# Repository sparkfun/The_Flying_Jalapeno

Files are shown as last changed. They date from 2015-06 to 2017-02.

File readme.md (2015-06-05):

The Flying Jalapeno
=======

This is a generic testbed board that will act as the "brain and usual hardware" for 99% of testbeds. We currently design a ton of testbeds using the pro mini, but this requires us to also put more circuitry on the testbed itself. Since we use basically the same extra stuff on every testbed, it makes sense to have a custom board that includes all of this.

It will be strictly used in QC and production (a sub assembly). 

The title "The Flying Jalapeno". I know I'm a dork, but hey, might as well name it something fun. And why not be in honor of the best AVC team name ever??

The extra hardware necessary for most testbeds:

-2 adjustable vregs with high-side switches
-2 resistor groups used for pre-testing for shorts to GND
-2 IOs setup for capsense (basically just 10M resistors for each "send" line)
-Resistors in place for PASS/FAIL leds
-Larger Vreg for VCC, to make more current available as needed
-Universal connector (2/18 header) that will mate with future pogobeds. (The idea here is that most future pogobeds will be comprised of two things: (2) the FLying Jalapeno and (2) the custom pogopin hardware.
-1x6 SMD FTDI RA header for easy programming and debug

License Information
-------------------

All of the designs in this repo are public domain but you buy me a beer if you use this and we meet someday ([Beerware license](http://en.wikipedia.org/wiki/Beerware)).

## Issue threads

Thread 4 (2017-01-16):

Capsense Methodology and Design

ericorosel, 2017-01-16:
IMO the capsense methodology could be improved.

We could save IO by sharing a return pin for both built-in capsense pads. This would also allow that pin to be broken-out for use on another capsense pad if it is added to the test-bed PCB.

This brings up 2 potential (not really) issues that I can think of:

(1) I'm not sure the MEGA is capable of sharing return lines. I see no reason why it wouldn't be able to based on how capsense functions, but I have not officially verified this.

(2) If there is an issue with the capsense lines on the FJ then this could affect both capsense pads instead of just one. This is also not really an issue seeing as these subs get tested in production and would not pass functional testing anyways.

Closed 2020-05-06.

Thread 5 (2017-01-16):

Net Naming Changes for Ease of Use

ericorosel, 2017-01-16:
For nets currently named PB0, PB1, PB2, and PB3 it would be nice if the net names would also reflect the digital pins that they represent in the pin definitions for the chip in Arduino eg.  53/PB0, 52/PB1, etc.

IMO, this naming convention should also be carried over to all of the serial lines: RX1/TX1 - RX3/TX3. I think we can omit RX0 and TX0, as those lines are not broken out to the test-bed and are dedicated programming and debug lines for the FJ.

Closed 2020-05-06.

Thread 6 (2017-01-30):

Pre set pins and naming

ericorosel, 2017-01-30:
I don't see a need in naming pins 40-43 any thing other than just default LED. In the chance that these LEDs are used as something other than PASS/FAIL LEDs it creates unneeded confusion.

I say leave it up to the designer to name the net between the pin and the LED symbol using the net as a descriptor for LED function.

Closed 2020-05-06.

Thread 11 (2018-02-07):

Add a pretest circuit for testing of board VCC

ericorosel, 2018-02-07:
for test-boards with an on-board vreg, it would be nice to have a pretest circuit built into the FJ so that one could test the VCC line for shorts. This would also allow one to check for proper regulator function. I believe currently the pretest circuits are defaulted to v1 and v2.

I suppose you could connect VCC (post on-board vreg) to v1 or v2, not power up that line, and just utilize the pretest circuit, but it seems a little wonky... Especially with some of the power control issues we've seen in the past.

ericorosel, 2020-04-28:
I'm not sure this is worth doing. I will be breaking out the FJ VCC to a pin on the connector to run switches, etc.

Closed 2020-04-28.

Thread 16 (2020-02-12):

Remove PCA from design

ericorosel, 2020-02-12:
Having logic conversion hardwired into the FJ design is unnecessary and causes more issues than it helps. If logic conversion is necessary per an assembly, we can add the appropiate parts to the daughter board

ericorosel, 2020-05-06:
Removed from new design, can use the PCA recomended replacement or create a LL conversion circuit using N Channel mosfet and pullups.

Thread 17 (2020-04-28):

Additions for FJ rev

ericorosel, 2020-04-28:
-add pins that breakout the output of V1 and V2 before the switch - power aux pins
-swap jumper for switch controlling FJ logic level
-add freqread and freqcount pins from paul's lib (47 for count, 49 for measure)

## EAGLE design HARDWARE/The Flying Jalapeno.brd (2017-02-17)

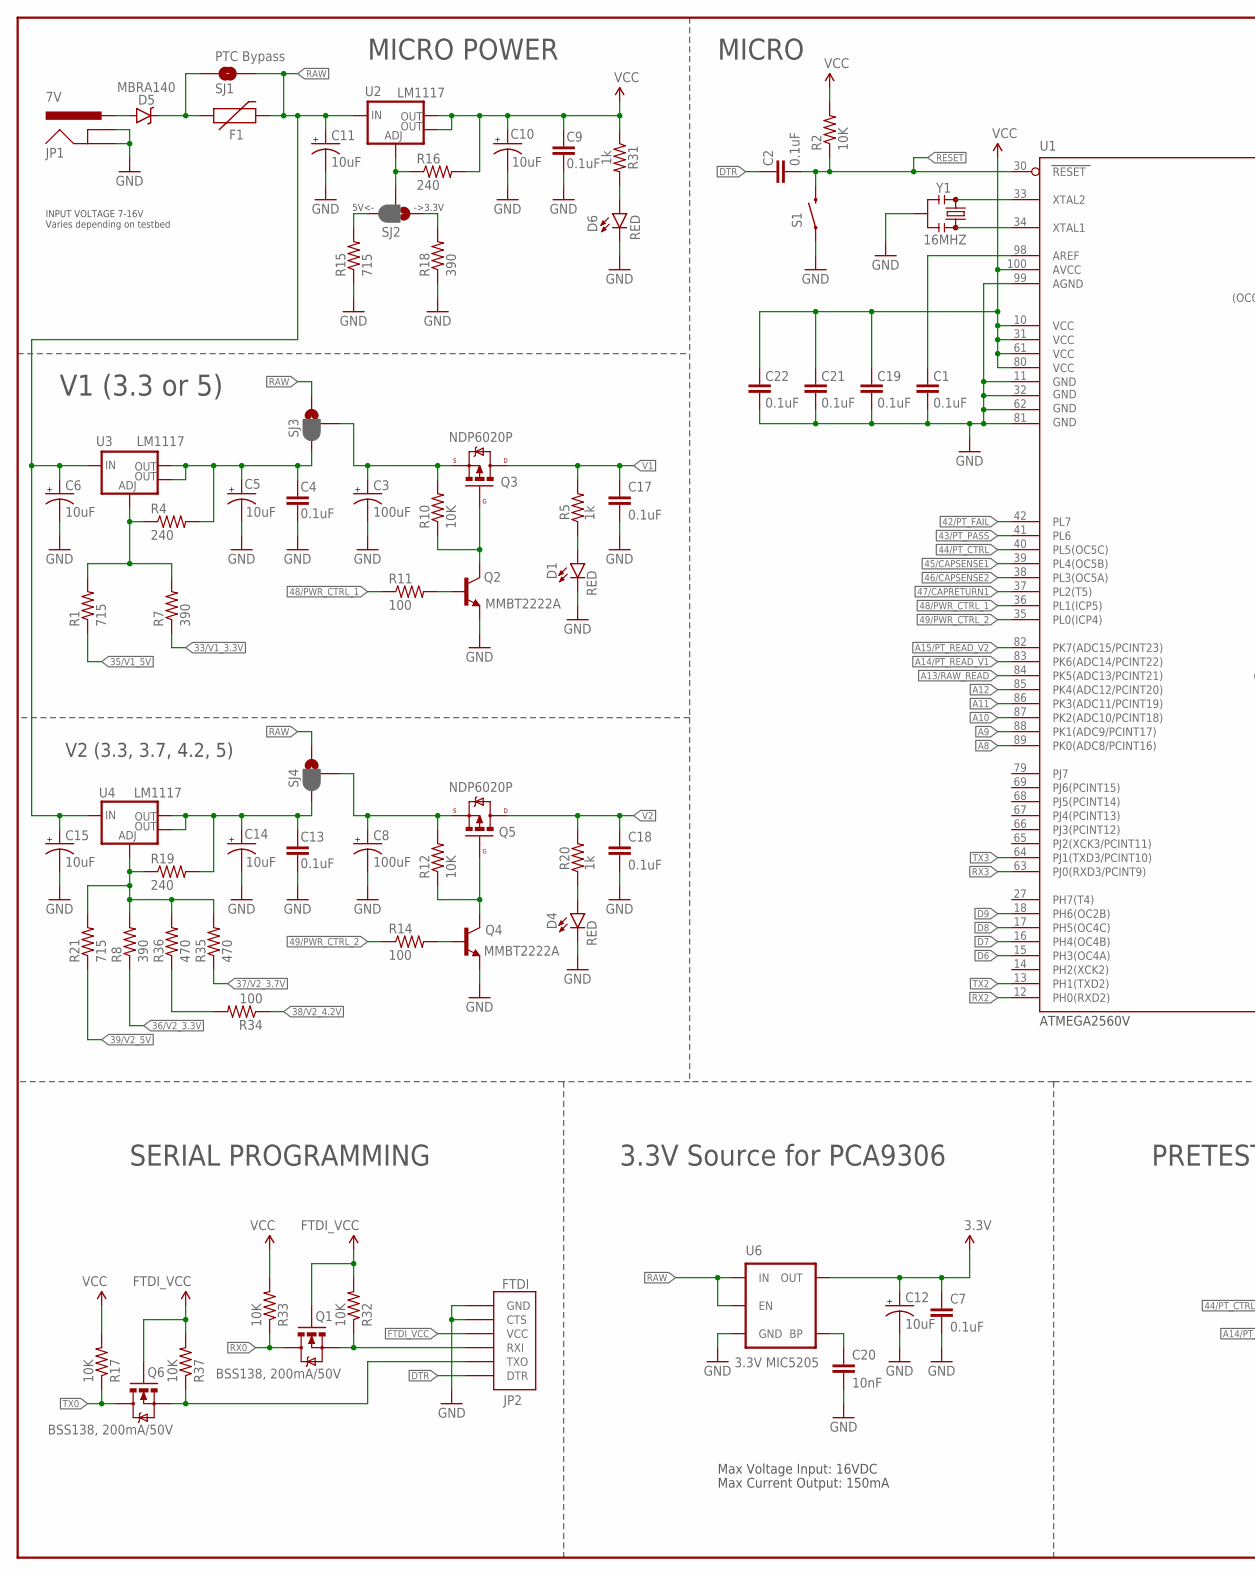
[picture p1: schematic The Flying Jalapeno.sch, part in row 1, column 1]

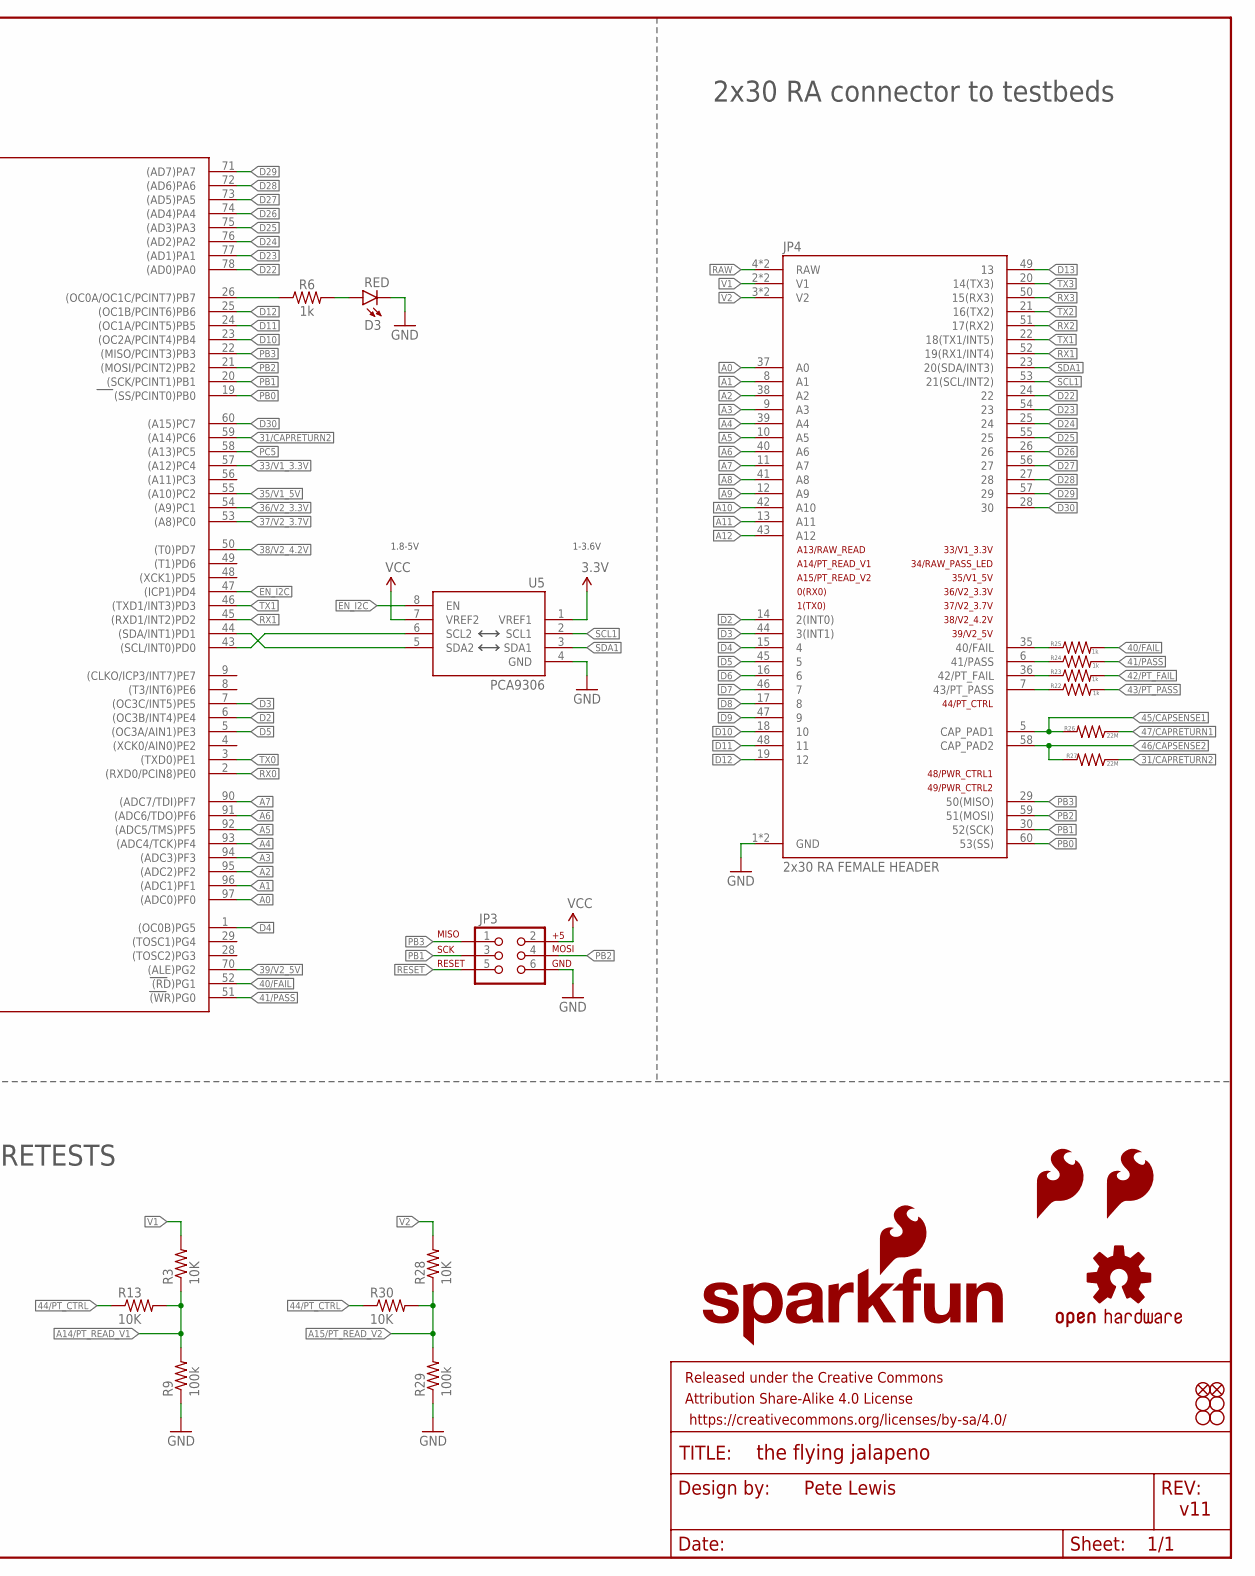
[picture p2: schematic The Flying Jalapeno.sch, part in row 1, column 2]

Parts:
C1, C2, C4, C7, C9, C13, C17, C18, C19, C21, C22: 0.1uF; 0603-CAP
C3, C8: 100uF; NIC_10X10.5_CAP
C5, C6, C10, C11, C14, C15: 10uF; EIA3216
C12: 10uF; 0603-POL
C20: 10nF; 0603
D1, D3, D4, D6: RED; LED-1206
D5: MBRA140; SMA-DIODE
F1: PTCTHERMISTOR1206; PTC-1206
FRAME1: FRAME-LEDGER; CREATIVE_COMMONS
JP1: 7V; POWER_JACK_PTH_LOCK
JP2: FTDI; FTDI_DEVICE_RA_SMT
JP3: AVR_SPI_PRG_6PTH; 2X3
JP4: 2x30 RA FEMALE HEADER; FLYING_JALAPENO_V3_F
JP5, JP8: FIDUCIALUFIDUCIAL; MICRO-FIDUCIAL
LOGO1: SFE_LOGO_NAME_FLAME.5_INCH; SFE_LOGO_NAME_FLAME_.5
LOGO2: SFE_LOGO_FLAME.3_INCH; SFE_LOGO_FLAME_.3
LOGO3: SFE_LOGO_FLAME.1_INCH; SFE_LOGO_FLAME_.1
LOGO4: OSHW-LOGOL; OSHW-LOGO-L
Q1, Q6: BSS138, 200mA/50V; SOT23-3
Q2, Q4: MMBT2222A; SOT23-3
Q3, Q5: NDP6020P; TO220V
R1, R15, R21: 715; 0603-RES
R2, R3, R10, R12, R13, R17, R28, R30, R32, R33, R37: 10K; 0603-RES
R4, R16, R19: 240; 0603-RES
R5, R6, R20, R22, R23, R24, R25, R31: 1k; 0603
R7, R8, R18: 390; 0603-RES
R9, R29: 100k; 0603-RES
R11, R14, R34: 100; 0603-RES
R26, R27: 22M; 0603-RES
R35, R36: 470; 0603-RES
S1: SWITCH-MOMENTARY-2SMD-REDUNDANT; TACTILE-SWITCH-SMD
SJ1: PTC Bypass; PAD-JUMPER-2-NO_NO_SILK
SJ2, SJ3, SJ4: JUMPER-PAD-3-2OF3_NC_BY_PASTE; PAD-JUMPER-3-2OF3_NC_BY_PASTE_YES_SILK_FULL_BOX
STANDOFF1, STANDOFF2, STANDOFF3, STANDOFF4: STAND-OFFTIGHT; STAND-OFF-TIGHT
U1: ATMEGA2560AU; TQFP100
U2, U3, U4: LM1117; SOT223
U5: PCA9306; PCA9306DC-1:1
U6: 3.3V MIC5205; SOT23-5
Y1: 16MHZ; RESONATOR-SMD

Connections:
3.3V: C7.1, C12.A (+), U5.1 (VREF1), U6.5 (OUT)
31/CAPRETURN2: R27.1, U1.59 ((A14)PC6)
33/V1_3.3V: R7.1, U1.57 ((A12)PC4)
35/V1_5V: R1.1, U1.55 ((A10)PC2)
36/V2_3.3V: R8.1, U1.54 ((A9)PC1)
37/V2_3.7V: R35.1, U1.53 ((A8)PC0)
38/V2_4.2V: R34.1, U1.50 ((T0)PD7)
39/V2_5V: R21.1, U1.70 ((ALE)PG2)
40/FAIL: R25.2, U1.52 ((RD)PG1)
41/PASS: R24.2, U1.51 ((WR)PG0)
42/PT_FAIL: R23.2, U1.42 (PL7)
43/PT_PASS: R22.2, U1.41 (PL6)
44/PT_CTRL: R13.1, R30.1, U1.40 (PL5(OC5C))
45/CAPSENSE1: JP4.5 (CAP_PAD1), R26.2, U1.39 (PL4(OC5B))
46/CAPSENSE2: JP4.58 (CAP_PAD2), R27.2, U1.38 (PL3(OC5A))
47/CAPRETURN1: R26.1, U1.37 (PL2(T5))
48/PWR_CTRL_1: R11.1, U1.36 (PL1(ICP5))
49/PWR_CTRL_2: R14.1, U1.35 (PL0(ICP4))
A0: JP4.37 (A0), U1.97 ((ADC0)PF0)
A1: JP4.8 (A1), U1.96 ((ADC1)PF1)
A2: JP4.38 (A2), U1.95 ((ADC2)PF2)
A3: JP4.9 (A3), U1.94 ((ADC3)PF3)
A4: JP4.39 (A4), U1.93 ((ADC4/TCK)PF4)
A5: JP4.10 (A5), U1.92 ((ADC5/TMS)PF5)
A6: JP4.40 (A6), U1.91 ((ADC6/TDO)PF6)
A7: JP4.11 (A7), U1.90 ((ADC7/TDI)PF7)
A8: JP4.41 (A8), U1.89 (PK0(ADC8/PCINT16))
A9: JP4.12 (A9), U1.88 (PK1(ADC9/PCINT17))
A10: JP4.42 (A10), U1.87 (PK2(ADC10/PCINT18))
A11: JP4.13 (A11), U1.86 (PK3(ADC11/PCINT19))
A12: JP4.43 (A12), U1.85 (PK4(ADC12/PCINT20))
A13/RAW_READ: U1.84 (PK5(ADC13/PCINT21))
A14/PT_READ_V1: R3.1, R9.2, R13.2, U1.83 (PK6(ADC14/PCINT22))
A15/PT_READ_V2: R28.1, R29.2, R30.2, U1.82 (PK7(ADC15/PCINT23))
AREF: C1.2, U1.98 (AREF)
D2: JP4.14 (2(INT0)), U1.6 ((OC3B/INT4)PE4)
D3: JP4.44 (3(INT1)), U1.7 ((OC3C/INT5)PE5)
D4: JP4.15 (4), U1.1 ((OC0B)PG5)
D5: JP4.45 (5), U1.5 ((OC3A/AIN1)PE3)
D6: JP4.16 (6), U1.15 (PH3(OC4A))
D7: JP4.46 (7), U1.16 (PH4(OC4B))
D8: JP4.17 (8), U1.17 (PH5(OC4C))
D9: JP4.47 (9), U1.18 (PH6(OC2B))
D10: JP4.18 (10), U1.23 ((OC2A/PCINT4)PB4)
D11: JP4.48 (11), U1.24 ((OC1A/PCINT5)PB5)
D12: JP4.19 (12), U1.25 ((OC1B/PCINT6)PB6)
D13: JP4.49 (13), R6.1, U1.26 ((OC0A/OC1C/PCINT7)PB7)
D22: JP4.24 (22), U1.78 ((AD0)PA0)
D23: JP4.54 (23), U1.77 ((AD1)PA1)
D24: JP4.25 (24), U1.76 ((AD2)PA2)
D25: JP4.55 (25), U1.75 ((AD3)PA3)
D26: JP4.26, U1.74 ((AD4)PA4)
D27: JP4.56 (27), U1.73 ((AD5)PA5)
D28: JP4.27 (28), U1.72 ((AD6)PA6)
D29: JP4.57 (29), U1.71 ((AD7)PA7)
D30: JP4.28 (30), U1.60 ((A15)PC7)
DTR: C2.2, JP2.1 (DTR)
EN_I2C: U1.47 ((ICP1)PD4), U5.8 (EN)
FTDI_VCC: JP2.4 (VCC), Q1.1 (G), Q6.1 (G), R32.2, R37.2
GND: C1.1, C3.-, C4.2, C5.C (-), C6.C (-), C7.2, C8.-, C9.2, C10.C (-), C11.C (-), C12.K (-), C13.2, C14.C (-), C15.C (-), C17.2, C18.2, C19.1, C20.2, C21.1, C22.1, D1.C, D3.C, D4.C, D6.C, JP1.GND, JP1.GNDBREAK, JP2.5 (CTS), JP2.6 (GND), JP3.6, JP4.1 (GND), JP4.31 (GND), Q2.2 (E), Q4.2 (E), R9.1, R15.1, R18.1, R29.1, S1.1, S1.2 (1), U1.11 (GND), U1.32 (GND1), U1.62 (GND2), U1.81 (GND3), U1.99 (AGND), U5.4 (GND), U6.2 (GND), Y1.2
unnamed: R34.2, R36.1
unnamed: U1.44 ((SDA/INT1)PD1), U5.5 (SDA2)
unnamed: R16.1, SJ2.2, U2.1 (ADJ)
unnamed: D3.A, R6.2
unnamed: D1.A, R5.1
unnamed: JP4.7 (43/PT_PASS), R22.1
unnamed: JP4.36 (42/PT_FAIL), R23.1
unnamed: Q2.1 (B), R11.2
unnamed: R1.2, R4.1, R7.2, U3.1 (ADJ)
unnamed: R8.2, R19.1, R21.2, R35.2, R36.2, U4.1 (ADJ)
unnamed: D4.A, R20.1
unnamed: Q2.3 (C), Q3.1 (G), R10.1
unnamed: Q4.1 (B), R14.2
unnamed: Q4.3 (C), Q5.1 (G), R12.1
unnamed: D5.C, F1.1, SJ1.1
unnamed: JP2.3 (RXI), Q1.2 (S), R32.1
unnamed: R18.2, SJ2.1
unnamed: R15.2, SJ2.3
unnamed: JP4.6 (41/PASS), R24.1
unnamed: JP4.35 (40/FAIL), R25.1
unnamed: C4.1, C5.A (+), R4.2, SJ3.3, U3.2 (OUT), U3.4 (OUT)
unnamed: C3.+, Q3.3 (S), R10.2, SJ3.2
unnamed: C8.+, Q5.3 (S), R12.2, SJ4.2
unnamed: D5.A, JP1.PWR
unnamed: D6.A, R31.2
unnamed: JP2.2 (TXO), Q6.2 (S), R37.1
unnamed: U1.43 ((SCL/INT0)PD0), U5.6 (SCL2)
unnamed: C20.1, U6.4 (BP)
unnamed: U1.33 (XTAL2), Y1.3
unnamed: U1.34 (XTAL1), Y1.1
PB0: JP4.60 (53(SS)), U1.19 ((SS/PCINT0)PB0)
PB1: JP3.3, JP4.30 (52(SCK)), U1.20 ((SCK/PCINT1)PB1)
PB2: JP3.4, JP4.59 (51(MOSI)), U1.21 ((MOSI/PCINT2)PB2)
PB3: JP3.1, JP4.29 (50(MISO)), U1.22 ((MISO/PCINT3)PB3)
PC5: U1.58 ((A13)PC5)
RAW: C6.A (+), C11.A (+), C15.A (+), F1.2, JP4.4 (RAW), JP4.34 (RAW), SJ1.2, SJ3.1, SJ4.1, U2.3 (IN), U3.3 (IN), U4.3 (IN), U6.1 (IN), U6.3 (EN)
RESET: C2.1, JP3.5, R2.1, S1.3 (2), S1.4 (2), U1.30 (RESET)
RX0: Q1.3 (D), R33.1, U1.2 ((RXD0/PCIN8)PE0)
RX1: JP4.52 (19(RX1/INT4)), U1.45 ((RXD1/INT2)PD2)
RX2: JP4.51 (17(RX2)), U1.12 (PH0(RXD2))
RX3: JP4.50 (15(RX3)), U1.63 (PJ0(RXD3/PCINT9))
SCL1: JP4.53 (21(SCL/INT2)), U5.2 (SCL1)
SDA1: JP4.23 (20(SDA/INT3)), U5.3 (SDA1)
TX0: Q6.3 (D), R17.1, U1.3 ((TXD0)PE1)
TX1: JP4.22 (18(TX1/INT5)), U1.46 ((TXD1/INT3)PD3)
TX2: JP4.21 (16(TX2)), U1.13 (PH1(TXD2))
TX3: JP4.20 (14(TX3)), U1.64 (PJ1(TXD3/PCINT10))
V1: C17.1, JP4.2 (V1), JP4.32 (V1), Q3.2 (D), R3.2, R5.2
V2: C18.1, JP4.3 (V2), JP4.33 (V2), Q5.2 (D), R20.2, R28.2
VCC: C9.1, C10.A (+), C19.2, C21.2, C22.2, JP3.2, R2.2, R16.2, R17.2, R31.1, R33.2, U1.10 (VCC), U1.31 (VCC1), U1.61 (VCC2), U1.80 (VCC3), U1.100 (AVCC), U2.2 (OUT), U2.4 (OUT), U5.7 (VREF2)
VREG2OUT: C13.1, C14.A (+), R19.2, SJ4.3, U4.2 (OUT), U4.4 (OUT)

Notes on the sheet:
PRETESTS
MICRO POWER
V1 (3.3 or 5)
V2 (3.3, 3.7, 4.2, 5)
SERIAL PROGRAMMING
MICRO
Pete Lewis
v11
ATMEGA2560V
2x30 RA connector to testbeds
INPUT VOLTAGE 7-16V Varies depending on testbed
->3.3V
5V<-
Max Voltage Input: 16VDC
Max Current Output: 150mA
1.8-5V
1-3.6V
3.3V Source for PCA9306

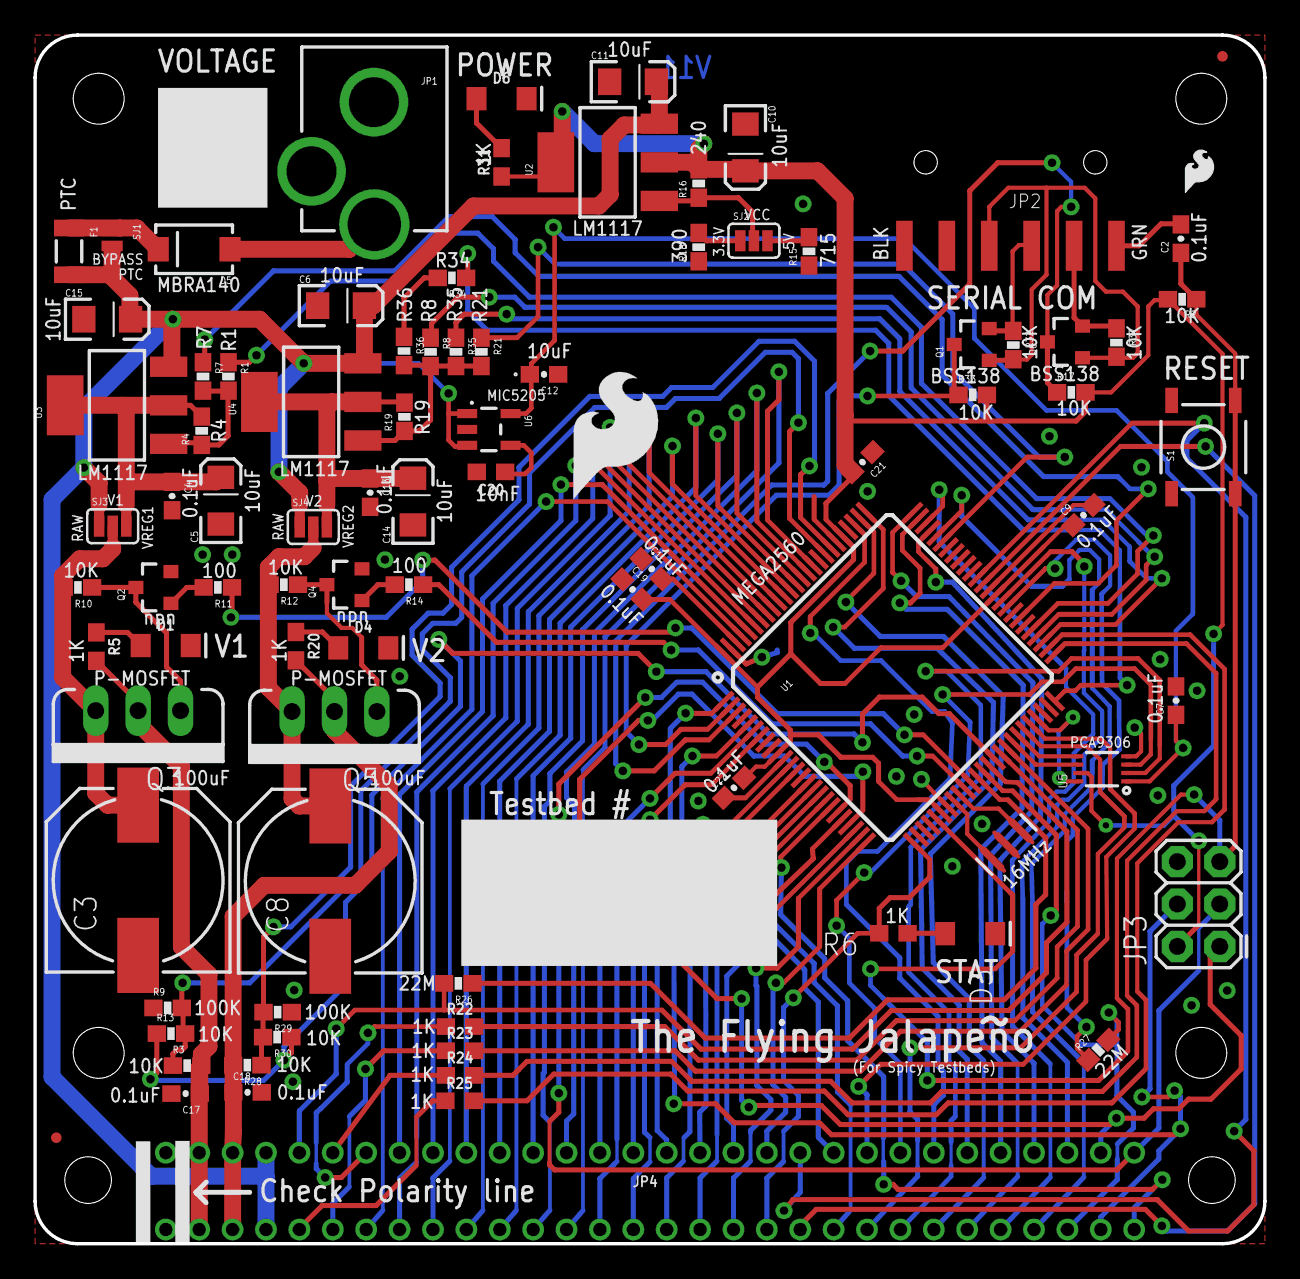
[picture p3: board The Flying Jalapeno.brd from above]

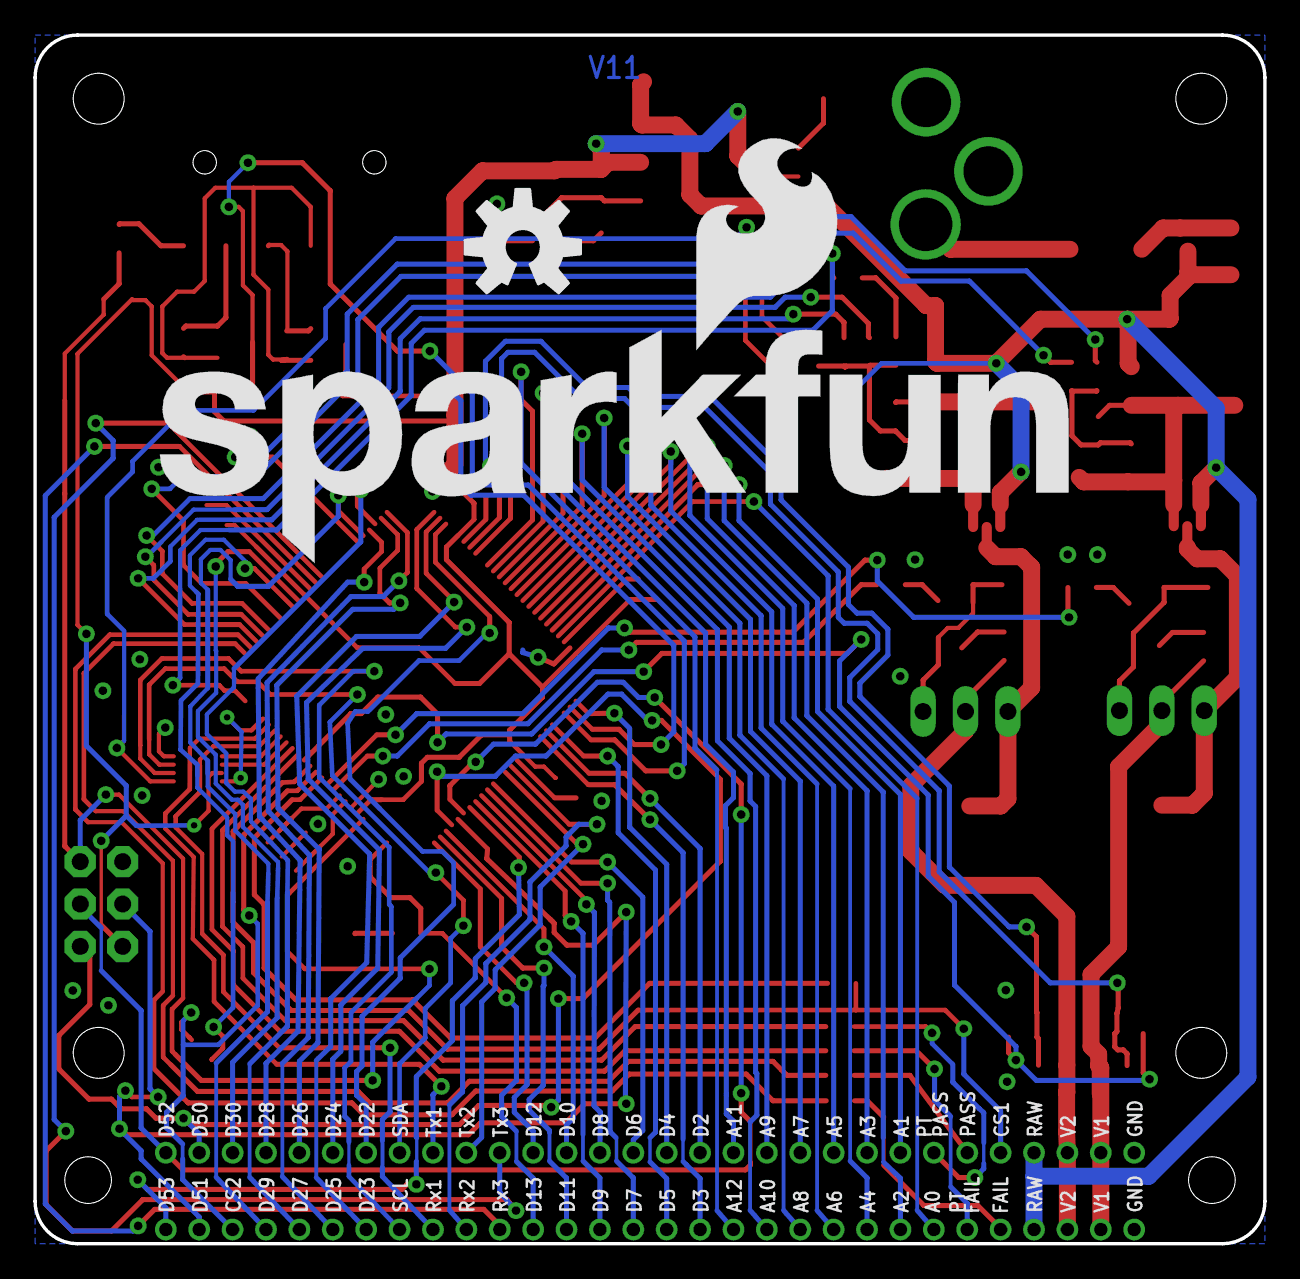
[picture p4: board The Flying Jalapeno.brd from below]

Board: 2 copper layers, 73.7 x 72.4 mm, 97 parts (2 on the bottom side), 109 nets.

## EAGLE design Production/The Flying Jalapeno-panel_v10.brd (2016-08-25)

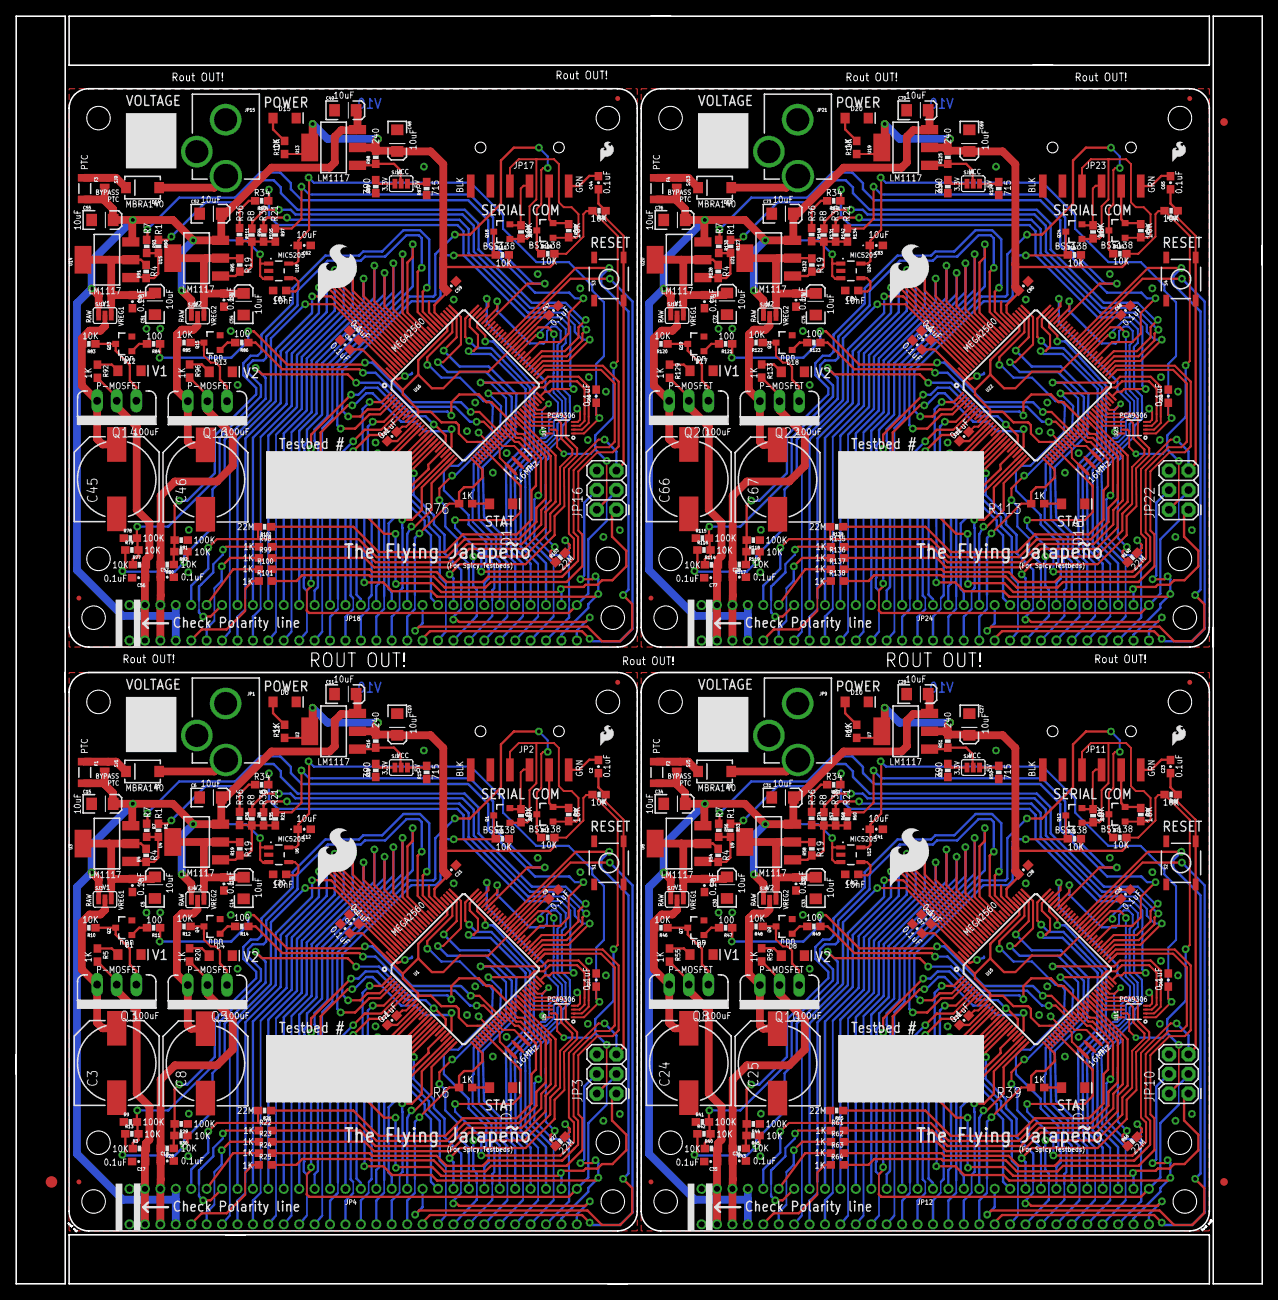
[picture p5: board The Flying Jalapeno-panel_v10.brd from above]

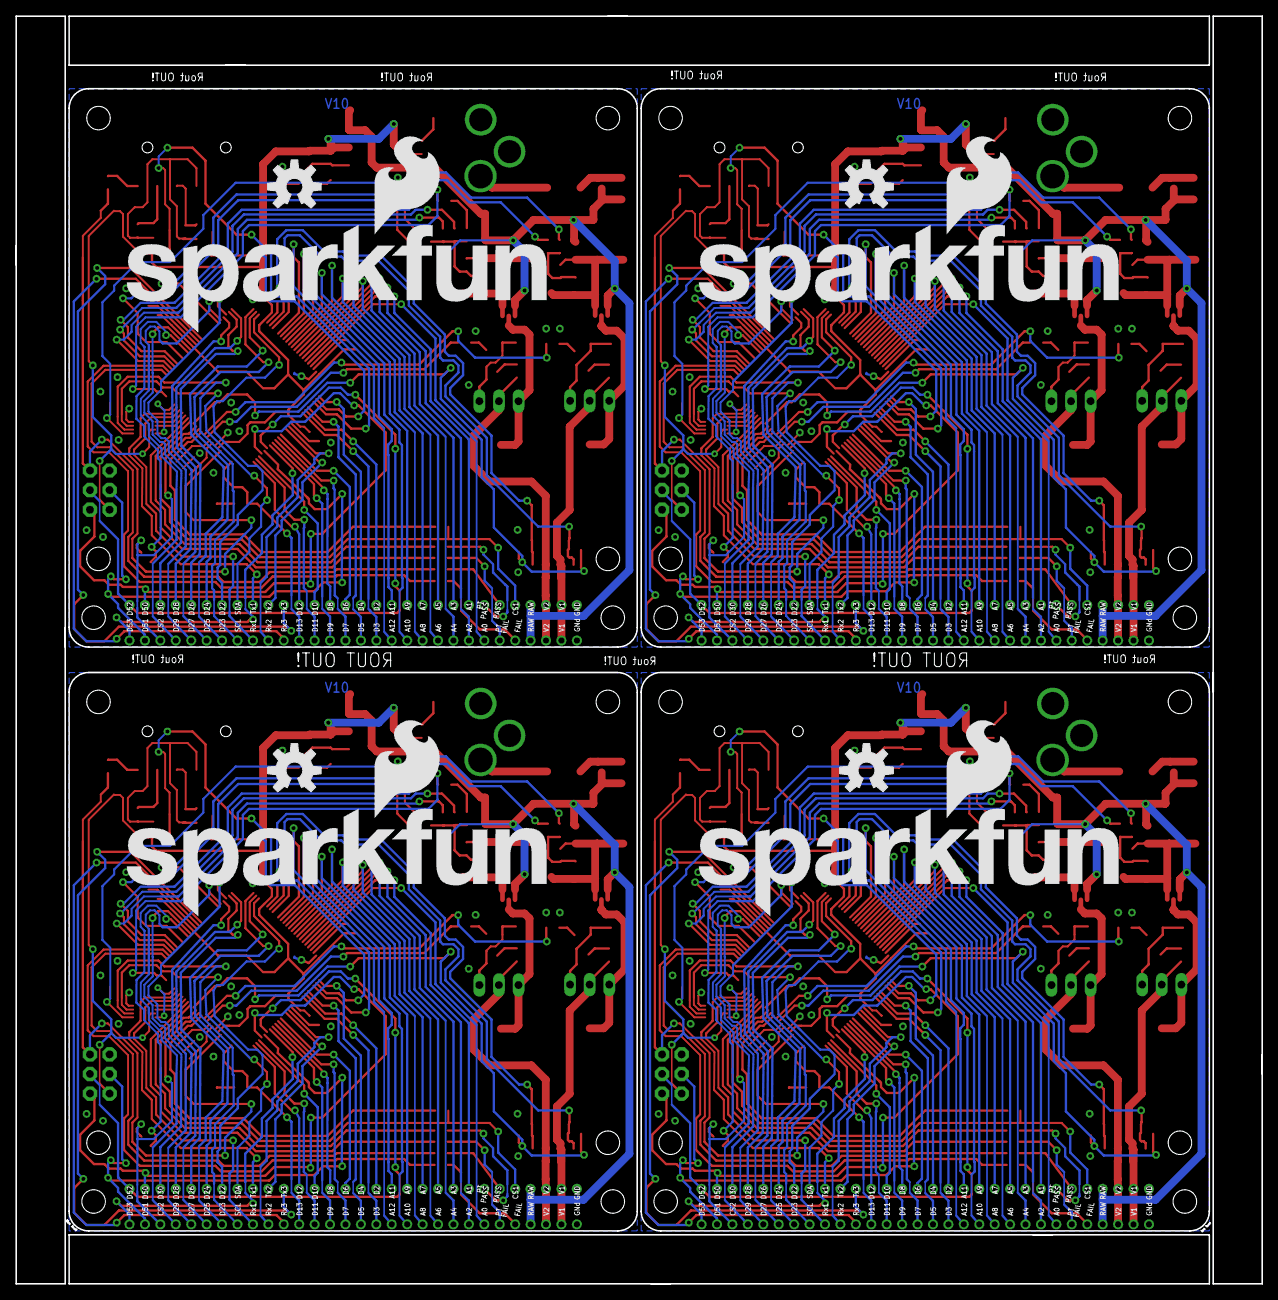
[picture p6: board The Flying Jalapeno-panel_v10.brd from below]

Board: 2 copper layers, 161.5 x 164.3 mm, 387 parts (8 on the bottom side), 436 nets.

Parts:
C1, C2, C4, C7, C9, C13, C16, C17, C18, C19, C21, C22, C23, C26, C29, C32, C35, C36, C37, C38, C39, C40, C43, C44, C47, C50, C53, C56, C57, C58, C59, C60, C61, C64, C65, C68, C71, C74, C77, C78, C79, C80, C81, C82: 0.1uF; 0603-CAP
C3, C8, C24, C25, C45, C46, C66, C67: 100uF; NIC_10X10.5_CAP
C5, C6, C10, C11, C14, C15, C27, C28, C30, C31, C33, C34, C48, C49, C51, C52, C54, C55, C69, C70, C72, C73, C75, C76: 10uF; EIA3216
C12, C41, C62, C83: 10uF; 0603-POL
C20, C42, C63, C84: 10nF; 0603
D1, D2, D3, D4, D6, D7, D8, D10, D11, D12, D13, D15, D16, D17, D18, D20: RED; LED-1206
D5, D9, D14, D19: MBRA140; SMA-DIODE
E$1: FIDUCIAL-1.5X3
E$7, E$8: FIDUCIAL-1X2
F1, F2, F3, F4: PTC-1206
JP1, JP9, JP15, JP21: 7V; POWER_JACK_PTH_LOCK
JP2, JP11, JP17, JP23: FTDI; FTDI_DEVICE_RA_SMT
JP3, JP10, JP16, JP22: 2X3
JP4, JP12, JP18, JP24: 2x30 RA FEMALE HEADER; FLYING_JALAPENO_V2_F
JP5, JP6, JP7, JP8, JP13, JP14, JP19, JP20: FIDUCIALUFIDUCIAL; MICRO-FIDUCIAL
LOGO1, LOGO5, LOGO9, LOGO13: SFE_LOGO_NAME_FLAME.5_INCH; SFE_LOGO_NAME_FLAME_.5
LOGO2, LOGO8, LOGO12, LOGO16: SFE_LOGO_FLAME.3_INCH; SFE_LOGO_FLAME_.3
LOGO3, LOGO6, LOGO10, LOGO14: SFE_LOGO_FLAME.1_INCH; SFE_LOGO_FLAME_.1
LOGO4, LOGO7, LOGO11, LOGO15: OSHW-LOGOL; OSHW-LOGO-L
Q1, Q6, Q11, Q12, Q17, Q18, Q23, Q24: BSS138, 200mA/50V; SOT23-3
Q2, Q4, Q7, Q9, Q13, Q15, Q19, Q21: MMBT2222A; SOT23-3
Q3, Q5, Q8, Q10, Q14, Q16, Q20, Q22: NDP6020P; TO220V
R1, R15, R21, R50, R53, R60, R87, R90, R97, R124, R127, R134: 715; 0603-RES
R2, R3, R10, R12, R13, R17, R28, R30, R32, R33, R37, R38, R40, R42, R43, R45, R46, R48, R70, R71, R72, R73, R75, R77, R79, R80, R82, R83, R85, R107, R108, R109, R110, R112, R114, R116, R117, R119, R120, R122, R144, R145, R146, R147: 10K; 0603-RES
R4, R16, R19, R51, R54, R58, R88, R91, R95, R125, R128, R132: 240; 0603-RES
R5, R6, R20, R22, R23, R24, R25, R31, R39, R55, R59, R61, R62, R63, R64, R69, R76, R92, R96, R98, R99, R100, R101, R106, R113, R129, R133, R135, R136, R137, R138, R143: 1k; 0603
R7, R8, R18, R52, R56, R57, R89, R93, R94, R126, R130, R131: 390; 0603-RES
R9, R29, R41, R44, R78, R81, R115, R118: 100k; 0603-RES
R11, R14, R34, R47, R49, R67, R84, R86, R104, R121, R123, R141: 100; 0603-RES
R26, R27, R65, R66, R102, R103, R139, R140: 22M; 0603-RES
R35, R36, R68, R74, R105, R111, R142, R148: 470; 0603-RES
S1, S2, S3, S4: TACTILE-SWITCH-SMD
SJ1, SJ5, SJ9, SJ13: PTC Bypass; PAD-JUMPER-2-NO_NO_SILK
SJ2, SJ3, SJ4, SJ6, SJ7, SJ8, SJ10, SJ11, SJ12, SJ14, SJ15, SJ16: PAD-JUMPER-3-2OF3_NC_BY_PASTE_YES_SILK_FULL_BOX
STANDOFF1, STANDOFF2, STANDOFF3, STANDOFF4, STANDOFF5, STANDOFF6, STANDOFF7, STANDOFF8, STANDOFF9, STANDOFF10, STANDOFF11, STANDOFF12, STANDOFF13, STANDOFF14, STANDOFF15, STANDOFF16: STAND-OFFTIGHT; STAND-OFF-TIGHT
U1, U10, U16, U22: ATMEGA2560AU; TQFP100
U2, U3, U4, U7, U8, U9, U13, U14, U15, U19, U20, U21: LM1117; SOT223
U5, U11, U17, U23: PCA9306; PCA9306DC-1:1
U6, U12, U18, U24: 3.3V MIC5205; SOT23-5
Y1, Y2, Y3, Y4: 16MHZ; RESONATOR-SMD

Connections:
3.3V: C7.1, C12.A, U5.1, U6.5
3.3V1: C40.1, C41.A, U11.1, U12.5
3.3V2: C61.1, C62.A, U17.1, U18.5
3.3V3: C82.1, C83.A, U23.1, U24.5
31/CAPRETURN1: R66.1, U10.59
31/CAPRETURN2: R27.1, U1.59
31/CAPRETURN3: R103.1, U16.59
31/CAPRETURN4: R140.1, U22.59
33/V1_3.3V: R7.1, U1.57
33/V1_3.3V1: R56.1, U10.57
33/V1_3.3V2: R93.1, U16.57
33/V1_3.3V3: R130.1, U22.57
35/V1_5V: R1.1, U1.55
35/V1_5V1: R53.1, U10.55
35/V1_5V2: R90.1, U16.55
35/V1_5V3: R127.1, U22.55
36/V2_3.3V: R8.1, U1.54
36/V2_3.3V1: R57.1, U10.54
36/V2_3.3V2: R94.1, U16.54
36/V2_3.3V3: R131.1, U22.54
37/V2_3.7V: R35.1, U1.53
37/V2_3.7V1: R68.1, U10.53
37/V2_3.7V2: R105.1, U16.53
37/V2_3.7V3: R142.1, U22.53
38/V2_4.2V: R34.1, U1.50
38/V2_4.2V1: R67.1, U10.50
38/V2_4.2V2: R104.1, U16.50
38/V2_4.2V3: R141.1, U22.50
39/V2_5V: R21.1, U1.70
39/V2_5V1: R60.1, U10.70
39/V2_5V2: R97.1, U16.70
39/V2_5V3: R134.1, U22.70
40/FAIL: R25.2, U1.52
40/FAIL1: R64.2, U10.52
40/FAIL2: R101.2, U16.52
40/FAIL3: R138.2, U22.52
41/PASS: R24.2, U1.51
41/PASS1: R63.2, U10.51
41/PASS2: R100.2, U16.51
41/PASS3: R137.2, U22.51
42/PT_FAIL: R23.2, U1.42
42/PT_FAIL1: R62.2, U10.42
42/PT_FAIL2: R99.2, U16.42
42/PT_FAIL3: R136.2, U22.42
43/PT_PASS: R22.2, U1.41
43/PT_PASS1: R61.2, U10.41
43/PT_PASS2: R98.2, U16.41
43/PT_PASS3: R135.2, U22.41
44/PT_CTRL: R13.1, R30.1, U1.40
44/PT_CTRL1: R42.1, R45.1, U10.40
44/PT_CTRL2: R79.1, R82.1, U16.40
44/PT_CTRL3: R116.1, R119.1, U22.40
45/CAPSENSE1: JP4.5, R26.2, U1.39
45/CAPSENSE2: JP12.5, R65.2, U10.39
45/CAPSENSE3: JP18.5, R102.2, U16.39
45/CAPSENSE4: JP24.5, R139.2, U22.39
46/CAPSENSE1: JP12.58, R66.2, U10.38
46/CAPSENSE2: JP4.58, R27.2, U1.38
46/CAPSENSE3: JP18.58, R103.2, U16.38
46/CAPSENSE4: JP24.58, R140.2, U22.38
47/CAPRETURN1: R26.1, U1.37
47/CAPRETURN2: R65.1, U10.37
47/CAPRETURN3: R102.1, U16.37
47/CAPRETURN4: R139.1, U22.37
48/PWR_CTRL1: R11.1, U1.36
48/PWR_CTRL2: R47.1, U10.36
48/PWR_CTRL3: R84.1, U16.36
48/PWR_CTRL4: R121.1, U22.36
49/PWR_CTRL1: R49.1, U10.35
49/PWR_CTRL2: R14.1, U1.35
49/PWR_CTRL3: R86.1, U16.35
49/PWR_CTRL4: R123.1, U22.35
A0: JP4.37, U1.97
A1: JP4.8, U1.96
A2: JP4.38, U1.95
A3: JP4.9, U1.94
A4: JP4.39, U1.93
A5: JP4.10, U1.92
A6: JP4.40, U1.91
A7: JP4.11, U1.90
A8: JP4.41, U1.89
A9: JP4.12, U1.88
A10: JP4.42, U1.87
A11: JP4.13, U1.86
A12: JP4.43, U1.85
A13: JP12.10, U10.92
A14: JP12.39, U10.93
A14/PT_READ_V1: R3.1, R9.2, R13.2, U1.83
A14/PT_READ_V2: R40.1, R41.2, R42.2, U10.83
A14/PT_READ_V3: R77.1, R78.2, R79.2, U16.83
A14/PT_READ_V4: R114.1, R115.2, R116.2, U22.83
A15: JP12.9, U10.94
A15/PT_READ_V1: R43.1, R44.2, R45.2, U10.82
A15/PT_READ_V2: R28.1, R29.2, R30.2, U1.82
A15/PT_READ_V3: R80.1, R81.2, R82.2, U16.82
A15/PT_READ_V4: R117.1, R118.2, R119.2, U22.82
A16: JP12.38, U10.95
A17: JP12.8, U10.96
A18: JP12.37, U10.97
A19: JP12.43, U10.85
A20: JP12.13, U10.86
A21: JP12.42, U10.87
A22: JP12.12, U10.88
A23: JP12.41, U10.89
A24: JP12.40, U10.91
A25: JP12.11, U10.90
A26: JP18.10, U16.92
A27: JP18.39, U16.93
A28: JP18.9, U16.94
A29: JP18.38, U16.95
A30: JP18.8, U16.96
A31: JP18.37, U16.97
A32: JP18.43, U16.85
A33: JP18.13, U16.86
A34: JP18.42, U16.87
A35: JP18.12, U16.88
A36: JP18.41, U16.89
A37: JP18.40, U16.91
A38: JP18.11, U16.90
A39: JP24.10, U22.92
A40: JP24.39, U22.93
A41: JP24.9, U22.94
A42: JP24.38, U22.95
A43: JP24.8, U22.96
A44: JP24.37, U22.97
A45: JP24.43, U22.85
A46: JP24.13, U22.86
A47: JP24.42, U22.87
A48: JP24.12, U22.88
A49: JP24.41, U22.89
A50: JP24.40, U22.91
A51: JP24.11, U22.90
AREF: C1.2, U1.98
AREF1: C16.2, U10.98
AREF2: C43.2, U16.98
AREF3: C64.2, U22.98
D1: JP12.47, U10.18
D2: JP4.14, U1.6
D3: JP4.44, U1.7
D4: JP4.15, U1.1
D5: JP4.45, U1.5
D6: JP4.16, U1.15
D7: JP4.46, U1.16
D8: JP4.17, U1.17
D9: JP4.47, U1.18
D10: JP4.18, U1.23
D11: JP4.48, U1.24
D12: JP4.19, U1.25
D13: JP4.49, R6.1, U1.26
D14: JP12.17, U10.17
D15: JP12.46, U10.16
D16: JP12.16, U10.15
D17: JP12.15, U10.1
D18: JP12.45, U10.5
D19: JP12.14, U10.6
D20: JP12.44, U10.7
D21: JP12.28, U10.60
D22: JP4.24, U1.78
D23: JP4.54, U1.77
D24: JP4.25, U1.76
D25: JP4.55, U1.75
D26: JP4.26, U1.74
D27: JP4.56, U1.73
D28: JP4.27, U1.72
D29: JP4.57, U1.71
D30: JP4.28, U1.60
D31: JP12.18, U10.23
D32: JP12.48, U10.24
D33: JP12.19, U10.25
D34: JP12.49, R39.1, U10.26
D35: JP12.24, U10.78
D36: JP12.25, U10.76
D37: JP12.55, U10.75
D38: JP12.26, U10.74
D39: JP12.56, U10.73
D40: JP12.27, U10.72
D41: JP12.57, U10.71
D42: JP12.54, U10.77
D43: JP18.47, U16.18
D44: JP18.17, U16.17
D45: JP18.46, U16.16
D46: JP18.16, U16.15
D47: JP18.15, U16.1
D48: JP18.45, U16.5
D49: JP18.14, U16.6
D50: JP18.44, U16.7
D51: JP18.28, U16.60
D52: JP18.18, U16.23
D53: JP18.48, U16.24
D54: JP18.19, U16.25
D55: JP18.49, R76.1, U16.26
D56: JP18.24, U16.78
D57: JP18.25, U16.76
D58: JP18.55, U16.75
D59: JP18.26, U16.74
D60: JP18.56, U16.73
D61: JP18.27, U16.72
D62: JP18.57, U16.71
D63: JP18.54, U16.77
D64: JP24.47, U22.18
D65: JP24.17, U22.17
D66: JP24.46, U22.16
D67: JP24.16, U22.15
D68: JP24.15, U22.1
D69: JP24.45, U22.5
D70: JP24.14, U22.6
D71: JP24.44, U22.7
D72: JP24.28, U22.60
D73: JP24.18, U22.23
D74: JP24.48, U22.24
D75: JP24.19, U22.25
D76: JP24.49, R113.1, U22.26
D77: JP24.24, U22.78
D78: JP24.25, U22.76
D79: JP24.55, U22.75
D80: JP24.26, U22.74
D81: JP24.56, U22.73
D82: JP24.27, U22.72
D83: JP24.57, U22.71
D84: JP24.54, U22.77
DTR: C2.2, JP2.1
DTR1: C23.2, JP11.1
DTR2: C44.2, JP17.1
DTR3: C65.2, JP23.1
EN_I2C: U1.47, U5.8
EN_I2C1: U10.47, U11.8
EN_I2C2: U16.47, U17.8
EN_I2C3: U22.47, U23.8
FTDI_VCC: JP2.4, Q1.1, Q6.1, R32.2, R37.2
FTDI_VCC1: JP11.4, Q11.1, Q12.1, R70.2, R72.2
FTDI_VCC2: JP17.4, Q17.1, Q18.1, R107.2, R109.2
FTDI_VCC3: JP23.4, Q23.1, Q24.1, R144.2, R146.2
GND: C1.1, C3.-, C4.2, C5.C, C6.C, C7.2, C8.-, C9.2, C10.C, C11.C, C12.K, C13.2, C14.C, C15.C, C17.2, C18.2, C19.1, C20.2, C21.1, C22.1, D1.C, D3.C, D4.C, D6.C, JP1.GND, JP1.GNDBREAK, JP2.5, JP2.6, JP3.6, JP4.1, JP4.31, Q2.2, Q4.2, R9.1, R15.1, R18.1, R29.1, S1.1, S1.2, U1.11, U1.32, U1.62, U1.81, U1.99, U5.4, U6.2, Y1.2
GND1: C16.1, C24.-, C25.-, C26.2, C27.C, C28.C, C29.2, C30.C, C31.C, C32.2, C33.C, C34.C, C35.2, C36.2, C37.1, C38.1, C39.1, C40.2, C41.K, C42.2, D2.C, D7.C, D8.C, D10.C, JP9.GND, JP9.GNDBREAK, JP10.6, JP11.5, JP11.6, JP12.1, JP12.31, Q7.2, Q9.2, R41.1, R44.1, R50.1, R52.1, S2.1, S2.2, U10.11, U10.32, U10.62, U10.81, U10.99, U11.4, U12.2, Y2.2
GND2: C43.1, C45.-, C46.-, C47.2, C48.C, C49.C, C50.2, C51.C, C52.C, C53.2, C54.C, C55.C, C56.2, C57.2, C58.1, C59.1, C60.1, C61.2, C62.K, C63.2, D11.C, D12.C, D13.C, D15.C, JP15.GND, JP15.GNDBREAK, JP16.6, JP17.5, JP17.6, JP18.1, JP18.31, Q13.2, Q15.2, R78.1, R81.1, R87.1, R89.1, S3.1, S3.2, U16.11, U16.32, U16.62, U16.81, U16.99, U17.4, U18.2, Y3.2
GND3: C64.1, C66.-, C67.-, C68.2, C69.C, C70.C, C71.2, C72.C, C73.C, C74.2, C75.C, C76.C, C77.2, C78.2, C79.1, C80.1, C81.1, C82.2, C83.K, C84.2, D16.C, D17.C, D18.C, D20.C, JP21.GND, JP21.GNDBREAK, JP22.6, JP23.5, JP23.6, JP24.1, JP24.31, Q19.2, Q21.2, R115.1, R118.1, R124.1, R126.1, S4.1, S4.2, U22.11, U22.32, U22.62, U22.81, U22.99, U23.4, U24.2, Y4.2
unnamed: R34.2, R36.1
unnamed: U1.44, U5.5
unnamed: R16.1, SJ2.2, U2.1
unnamed: D3.A, R6.2
unnamed: D1.A, R5.1
unnamed: JP4.7, R22.1
unnamed: JP4.36, R23.1
unnamed: Q2.1, R11.2
unnamed: R1.2, R4.1, R7.2, U3.1
unnamed: R8.2, R19.1, R21.2, R35.2, R36.2, U4.1
unnamed: D4.A, R20.1
unnamed: Q2.3, Q3.1, R10.1
unnamed: Q4.1, R14.2
unnamed: Q4.3, Q5.1, R12.1
unnamed: D5.C, F1.1, SJ1.1
unnamed: JP2.3, Q1.2, R32.1
unnamed: R18.2, SJ2.1
unnamed: R15.2, SJ2.3
unnamed: JP4.6, R24.1
unnamed: JP4.35, R25.1
unnamed: C4.1, C5.A, R4.2, SJ3.3, U3.2, U3.4
unnamed: C3.+, Q3.3, R10.2, SJ3.2
unnamed: C8.+, Q5.3, R12.2, SJ4.2
unnamed: D5.A, JP1.PWR
unnamed: D6.A, R31.2
unnamed: JP2.2, Q6.2, R37.1
unnamed: U1.43, U5.6
unnamed: C20.1, U6.4
unnamed: Q7.1, R47.2
unnamed: Q7.3, Q8.1, R46.1
unnamed: Q9.1, R49.2
unnamed: Q9.3, Q10.1, R48.1
unnamed: D9.C, F2.1, SJ5.1
unnamed: R51.1, SJ6.2, U7.1
unnamed: R52.2, SJ6.1
unnamed: R50.2, SJ6.3
unnamed: D7.A, R55.1
unnamed: R53.2, R54.1, R56.2, U8.1
unnamed: R57.2, R58.1, R60.2, R68.2, R74.2, U9.1
unnamed: D8.A, R59.1
unnamed: C29.1, C30.A, R54.2, SJ7.3, U8.2, U8.4
unnamed: C24.+, Q8.3, R46.2, SJ7.2
unnamed: C25.+, Q10.3, R48.2, SJ8.2
unnamed: D9.A, JP9.PWR
unnamed: U10.33, Y2.3
unnamed: U10.34, Y2.1
unnamed: D2.A, R39.2
unnamed: JP12.7, R61.1
unnamed: JP12.36, R62.1
unnamed: JP12.6, R63.1
unnamed: JP12.35, R64.1
unnamed: D10.A, R69.2
unnamed: JP11.3, Q12.2, R72.1
unnamed: JP11.2, Q11.2, R70.1
unnamed: R67.2, R74.1
unnamed: U10.44, U11.5
unnamed: U10.43, U11.6
unnamed: C42.1, U12.4
unnamed: Q13.1, R84.2
unnamed: Q13.3, Q14.1, R83.1
unnamed: Q15.1, R86.2
unnamed: Q15.3, Q16.1, R85.1
unnamed: D14.C, F3.1, SJ9.1
unnamed: R88.1, SJ10.2, U13.1
unnamed: R89.2, SJ10.1
unnamed: R87.2, SJ10.3
unnamed: D12.A, R92.1
unnamed: R90.2, R91.1, R93.2, U14.1
unnamed: R94.2, R95.1, R97.2, R105.2, R111.2, U15.1
unnamed: D13.A, R96.1
unnamed: C50.1, C51.A, R91.2, SJ11.3, U14.2, U14.4
unnamed: C45.+, Q14.3, R83.2, SJ11.2
unnamed: U1.33, Y1.3
unnamed: U1.34, Y1.1
unnamed: C46.+, Q16.3, R85.2, SJ12.2
unnamed: D14.A, JP15.PWR
unnamed: U16.33, Y3.3
unnamed: U16.34, Y3.1
unnamed: D11.A, R76.2
unnamed: JP18.7, R98.1
unnamed: JP18.36, R99.1
unnamed: JP18.6, R100.1
unnamed: JP18.35, R101.1
unnamed: D15.A, R106.2
unnamed: JP17.3, Q18.2, R109.1
unnamed: JP17.2, Q17.2, R107.1
unnamed: R104.2, R111.1
unnamed: U16.44, U17.5
unnamed: U16.43, U17.6
unnamed: C63.1, U18.4
unnamed: Q19.1, R121.2
unnamed: Q19.3, Q20.1, R120.1
unnamed: Q21.1, R123.2
unnamed: Q21.3, Q22.1, R122.1
unnamed: D19.C, F4.1, SJ13.1
unnamed: R125.1, SJ14.2, U19.1
unnamed: R126.2, SJ14.1
unnamed: R124.2, SJ14.3
unnamed: D17.A, R129.1
unnamed: R127.2, R128.1, R130.2, U20.1
unnamed: R131.2, R132.1, R134.2, R142.2, R148.2, U21.1
unnamed: D18.A, R133.1
unnamed: C71.1, C72.A, R128.2, SJ15.3, U20.2, U20.4
unnamed: C66.+, Q20.3, R120.2, SJ15.2
unnamed: C67.+, Q22.3, R122.2, SJ16.2
unnamed: D19.A, JP21.PWR
unnamed: U22.33, Y4.3
unnamed: U22.34, Y4.1
unnamed: D16.A, R113.2
unnamed: JP24.7, R135.1
unnamed: JP24.36, R136.1
unnamed: JP24.6, R137.1
unnamed: JP24.35, R138.1
unnamed: D20.A, R143.2
unnamed: JP23.3, Q24.2, R146.1
unnamed: JP23.2, Q23.2, R144.1
unnamed: R141.2, R148.1
unnamed: U22.44, U23.5
unnamed: U22.43, U23.6
unnamed: C84.1, U24.4
PB0: JP4.60, U1.19
PB1: JP3.3, JP4.30, U1.20
PB2: JP3.4, JP4.59, U1.21
PB3: JP3.1, JP4.29, U1.22
PB4: JP12.60, U10.19
PB5: JP10.3, JP12.30, U10.20
PB6: JP10.4, JP12.59, U10.21
PB7: JP10.1, JP12.29, U10.22
PB8: JP18.60, U16.19
PB9: JP16.3, JP18.30, U16.20
PB10: JP16.4, JP18.59, U16.21
PB11: JP16.1, JP18.29, U16.22
PB12: JP24.60, U22.19
PB13: JP22.3, JP24.30, U22.20
PB14: JP22.4, JP24.59, U22.21
PB15: JP22.1, JP24.29, U22.22
RAW: C6.A, C11.A, C15.A, F1.2, JP4.4, JP4.34, SJ1.2, SJ3.1, SJ4.1, U2.3, U3.3, U4.3, U6.1, U6.3
RAW1: C28.A, C31.A, C34.A, F2.2, JP12.4, JP12.34, SJ5.2, SJ7.1, SJ8.1, U7.3, U8.3, U9.3, U12.1, U12.3
RAW2: C49.A, C52.A, C55.A, F3.2, JP18.4, JP18.34, SJ9.2, SJ11.1, SJ12.1, U13.3, U14.3, U15.3, U18.1, U18.3
RAW3: C70.A, C73.A, C76.A, F4.2, JP24.4, JP24.34, SJ13.2, SJ15.1, SJ16.1, U19.3, U20.3, U21.3, U24.1, U24.3
RESET: C2.1, JP3.5, R2.1, S1.3, S1.4, U1.30
RESET1: C23.1, JP10.5, R38.1, S2.3, S2.4, U10.30
RESET2: C44.1, JP16.5, R75.1, S3.3, S3.4, U16.30
RESET3: C65.1, JP22.5, R112.1, S4.3, S4.4, U22.30
RX0: Q1.3, R33.1, U1.2
RX1: JP4.52, U1.45
RX2: JP4.51, U1.12
RX3: JP4.50, U1.63
RX4: JP12.50, U10.63
RX5: JP12.51, U10.12
RX6: Q12.3, R73.1, U10.2
RX7: JP12.52, U10.45
RX8: JP18.50, U16.63
RX9: JP18.51, U16.12
RX10: Q18.3, R110.1, U16.2
RX11: JP18.52, U16.45
RX12: JP24.50, U22.63
RX13: JP24.51, U22.12
RX14: Q24.3, R147.1, U22.2
RX15: JP24.52, U22.45
SCL1: JP4.53, U5.2
SCL2: JP12.53, U11.2
SCL3: JP18.53, U17.2
SCL4: JP24.53, U23.2
SDA1: JP4.23, U5.3
SDA2: JP12.23, U11.3
SDA3: JP18.23, U17.3
SDA4: JP24.23, U23.3
TX0: Q6.3, R17.1, U1.3
TX1: JP4.22, U1.46
TX2: JP4.21, U1.13
TX3: JP4.20, U1.64
TX4: JP12.20, U10.64
TX5: JP12.21, U10.13
TX6: JP12.22, U10.46
TX7: Q11.3, R71.1, U10.3
TX8: JP18.20, U16.64
TX9: JP18.21, U16.13
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

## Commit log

2015-06-05 added in v01 of eagle design
    [The Flying Jalapeno v01.brd, The Flying Jalapeno v01.sch]
2015-06-05 Power input Diode
    [The Flying Jalapeno v01.brd, The Flying Jalapeno v01.sch]
2015-06-05 Some PROD_IDS and moved to 100uF SMD caps
    [The Flying Jalapeno v01.brd, The Flying Jalapeno v01.sch]
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2015-06-05 more prod ids and some sch cleanup
    last thing that needs prod ids is the headers at the bottom, not sure if
    we're gonna go with break away or combining 10pin and 8pin pieces
    [The Flying Jalapeno v01.brd, The Flying Jalapeno v01.sch]
2015-06-17 pulled libraries to get lost devices
    Still re-thinking connector, might go with 2x20 RA M/F
    [The Flying Jalapeno v01.brd, The Flying Jalapeno v01.sch]
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2015-07-09 Moved to Mega2560 and 2x30 2mm connector
    device and packages for the 2x30 connector all live in the "local"
    sparkfun.lbr for now. I will push to testing.lbr soon.
    [The Flying Jalapeno v01.brd, The Flying Jalapeno v01.sch]
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2015-07-13 Modified Capsense pad device to use only 1 pin/pad
    I realized that I don't need the usual two lines for capsense buttons on
    this (SEND/RETURN). Because the resistors are going to live on the
    board, then the "button" on the testbed is only an extension of one net.
    Updated library devices to reflect this correction.
    [The Flying Jalapeno v01.brd, The Flying Jalapeno v01.sch]
2015-07-13 Cleaning up repo - deleting local libraries
    I commited the FJ device and new capsense to the testing library repo,
    and so no longer need them in here.
2015-07-14 finalized resistor values on lipo fake out vreg
    [The Flying Jalapeno v01.brd, The Flying Jalapeno v01.sch]
2015-07-14 Added labels to 2x30 connector
    also a lot of other small stuff as I went through the checklist
    [The Flying Jalapeno v01.brd, The Flying Jalapeno v01.sch]
2015-07-14 added labels to all parts
    [The Flying Jalapeno v01.brd]
2015-07-28 Fixed Rogue trace off of capsense2
    Thanks for catching this in your review Kade!
    [The Flying Jalapeno v01.brd]
2015-07-29 created bracket for mounting flaying jalapeno to testbeds
    [The Flying Jalapeno BRACKET v01.brd, The Flying Jalapeno BRACKET v01.sch]
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2016-03-17 adding some pass/fail led functionality
    setup as outpus automatically in initialise function.
    also fixed some power control functions.
    added some defines for LEDs in header file
2016-05-20 added in PCA9306 for I2C - still not netted or routed
    also added ignore for lock files
    [The Flying Jalapeno v02.brd, The Flying Jalapeno v02.sch]
2016-06-03 Placed/routed the PCA9306 into the design
    Still some silk labeling to do, and check that GND pours are as good as
    they can flow.
    [The Flying Jalapeno v02.brd, The Flying Jalapeno v02.sch]
2016-06-06 finished up routing and adjusted silk
    Added/updated silk to:
    Led resistors (stat and 4 others)- now are 1K
    MIC5205 3.3V vreg
    10uF pol cap
    10nF bypass cap - near vreg
    PCA9306
    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
    [The Flying Jalapeno v02.brd, The Flying Jalapeno v02.sch]
2016-06-06 removed RAW split test, moved pwr led from io to VCC
    [The Flying Jalapeno v02.brd, The Flying Jalapeno v02.sch]
2016-06-06 moved test bed # silk and box back into position
    [The Flying Jalapeno v02.brd]
2016-06-06 moved V1 and V2 leds resistors to 1K
    also update silk labeling
    also removed test point on 3.3V vreg output
    [The Flying Jalapeno v02.brd, The Flying Jalapeno v02.sch]
2016-06-06 removed bottom silk for optional I2C pullups
    They are no longer on this design, I will rely on internal pullups, or
    if the product has them, that should be good too.
    [The Flying Jalapeno v02.brd]
2016-06-06 cleaning up some routing
    [The Flying Jalapeno v02.brd]
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2016-06-06 added prod id part for smd 6 pin header (ftdi)
    [The Flying Jalapeno v02.brd, The Flying Jalapeno v02.sch]
2016-06-09 fixed rx/tx trace overlap problem
    I had previously swapped out the device for the newest version with PROD
    ID and it messed with my pin assignments resulting in changing copper. I
    assumed it wouldn't effect copper and failed to run the DRC again. Sorry
    I didn't see this before requesting a review.
    [The Flying Jalapeno v02.brd, The Flying Jalapeno v02.sch]
2016-06-14 added PROD_ID to FJ connector (JP4)
    [The Flying Jalapeno v02.brd, The Flying Jalapeno v02.sch]
2016-07-26 Adding in production testing stuff
    self test sketch and dummy hardware
    [The Flying Jalapeno DUMMY v01.brd, The Flying Jalapeno DUMMY v01.sch]
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2016-07-28 corrected Resistor names
    Some resistor names skipped in the 30s, now they increment correctly.
    [The Flying Jalapeno v02.brd, The Flying Jalapeno v02.sch]
2016-07-28 Switched to reference designators on resistors near adjustable vregs
    These values may change for special testbeds, and so an "R#" is more
    correct, and easier to reference the schematic.
    [The Flying Jalapeno v02.brd]
2016-07-28 enlarged the "testbed #" silk box
    [The Flying Jalapeno v02.brd]
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2016-07-28 replaced updated connector package in design
    [The Flying Jalapeno v02.brd, The Flying Jalapeno v02.sch]
2016-07-28 removed version number from eagle file name
    [The Flying Jalapeno.brd, The Flying Jalapeno.sch]
2016-07-28 incremented version number to v10
    in sch and brd
    Had to nudge traces around when I replaced the fj connector for the
    updated package.
    [The Flying Jalapeno.brd, The Flying Jalapeno.sch]
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2016-07-28 schematic cleanup - fit all into one frame
    [The Flying Jalapeno.sch]
2016-07-28 update red leds to correct part/prod_ids
    [The Flying Jalapeno.brd, The Flying Jalapeno.sch]
2016-07-28 removed a small rouge trace off of RAW, must have been from v01
    [The Flying Jalapeno.brd]
2016-07-28 small nudges to some traces to get nicer angles and removes some unnecessary kinks
    [The Flying Jalapeno.brd]
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2016-09-01 added V1/V2 leds on at end of test
    also added TB EAGLE folder, moved dummy in there
    [The Flying Jalapeno DUMMY v01.brd, The Flying Jalapeno DUMMY v01.sch]
2016-09-01 added programming jig eagle files
    [The Flying Jalapeno PB v01.brd, The Flying Jalapeno PB v01.sch, The Flying Jalapeno PF v01.brd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]
2016-09-01 Added cutouts in the PM to allow space for nylon standoffs
    had to mill these out on v01. Originally planned on testing without
    these populated.
    [The Flying Jalapeno PM v02.brd, The Flying Jalapeno PM v02.sch]
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2016-09-09 Changed "FJ Bracket" text to tplace
    also made the brd file have 8 copies, for quicker adding to QC panels
    when we order a tone of these.
    [The Flying Jalapeno BRACKET v01.brd, The Flying Jalapeno BRACKET v01.sch]
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2016-10-19 temporary manual testing of the PT circuit
    I will need to put this into another automated portion of the test (in
    the future), but to get through th IP, I just put this new code on, hit
    reset a few times, and jumpered V1 and V2 to GND verifying that the PT
    showed 486 correctly.
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2016-11-15 Adding examples. Fixing bug in powerTest.
    PowerTest could not fail because of &&. Reading can not be both smaller and larger than jumper_val.
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2016-11-21 Updating Bracket design to use 0.11 drill hits
    to keep consistent with our QC panel drill summary for NPTH
    [The Flying Jalapeno BRACKET v01.brd]
2016-11-21 removing bracket SCH file
    unnecessary to keep this, no device/symbols for this, so just need brd
    file for ordering.
    [The Flying Jalapeno BRACKET v01.sch]
2016-11-21 removing local temp libraries
    The FJ device has been rolled into SFE testing library. I'd rather only
    keep it in one place, to avoid version control wackiness.
2016-11-22 "custom" pretest function - send it spcific pins
    When you need more pre-tests for shorts to ground, use this function. It
    allows you to send a control pin and read pin, and returns true if all
    is good (no jumper).
2017-02-15 Fixed bPlace silk labels on 2x30 header
    These used to overlap onto the pth headers cutting a lot of the silk.
    This fixes issue #7
    Also nudged some vias and traces to ensure none of the silk gets cut.
    Also bumped silk up to 0.032, 18% (previously was 0.026). This should
    look really nice on the next round of pcbs.
    [The Flying Jalapeno.brd]
2017-02-15 changed version to v11, to keep things straight.
    [The Flying Jalapeno.brd, The Flying Jalapeno.sch]
2017-02-16 cleaning up net naming convention on 48/49
    "48/PWR_CTRL_V1" and "49/PWR_CTRL_V2".
    issue #3
    [The Flying Jalapeno.brd, The Flying Jalapeno.sch]
2017-02-17 Updated FJ device - symbol and package
    Symbol pins are now correctly named A0 and A1, they used to have A0/TX0
    and A1/RX0, which is incorrect and left over from the mega pro designs.
    Also, with this update to the device came a small update to the package.
    Only thing effected was the drill hits for the brackets are now the
    correct "tighter" size of 0.11".
    [The Flying Jalapeno.brd, The Flying Jalapeno.sch]
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2017-08-17 Deleting production testing stuff - moved to qcvault
    can be found in SUB-13059
    [The Flying Jalapeno DUMMY v01.brd, The Flying Jalapeno DUMMY v01.sch, The Flying Jalapeno PB v01.brd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]

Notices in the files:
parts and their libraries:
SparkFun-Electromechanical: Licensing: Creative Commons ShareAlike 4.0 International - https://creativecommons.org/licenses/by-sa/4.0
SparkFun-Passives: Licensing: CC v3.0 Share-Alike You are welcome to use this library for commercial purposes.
